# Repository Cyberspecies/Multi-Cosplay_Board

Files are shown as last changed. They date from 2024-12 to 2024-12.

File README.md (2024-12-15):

# Multi-Cosplay_Board
The board should be capable of driving nearly any electrically active cosplay suit or project including props. The system must also remain cheap and affordable with inter and extrapolation capabilities allowing it to be reducibly complex and still function. The software must also be easy to configure and implement (as this is a platform supported by [ARCOS](https://github.com/XCR1793/ARCOS)).

## Features
* Movement detection via the [ICM-20948](https://invensense.tdk.com/products/motion-tracking/9-axis/icm-20948/), which allows users to track their linear and angular accelerations for animations that require shaking, turning or any other activity requiring user displacement.
* Designed with a small form-factor which users can take advantage of by hiding the circuit board in tight spaces to not get it in the way of aesthetics.
* Fast processing core being the [ESP32-S3 Modules](https://www.espressif.com/en/products/socs/esp32) contains a 280Mhz dual core processor allowing partial asynchronous parallel calculations required for detecting user input and computing sequences at the same time whilst remaining as affordable as possible.

## Roadmap
* Milestone: Nothing Yet
* Work In Progress: Ideation & PCB Component Placement & Feature Integration
* Planned: MCB Version 1
* Planned: ARCOS Integration

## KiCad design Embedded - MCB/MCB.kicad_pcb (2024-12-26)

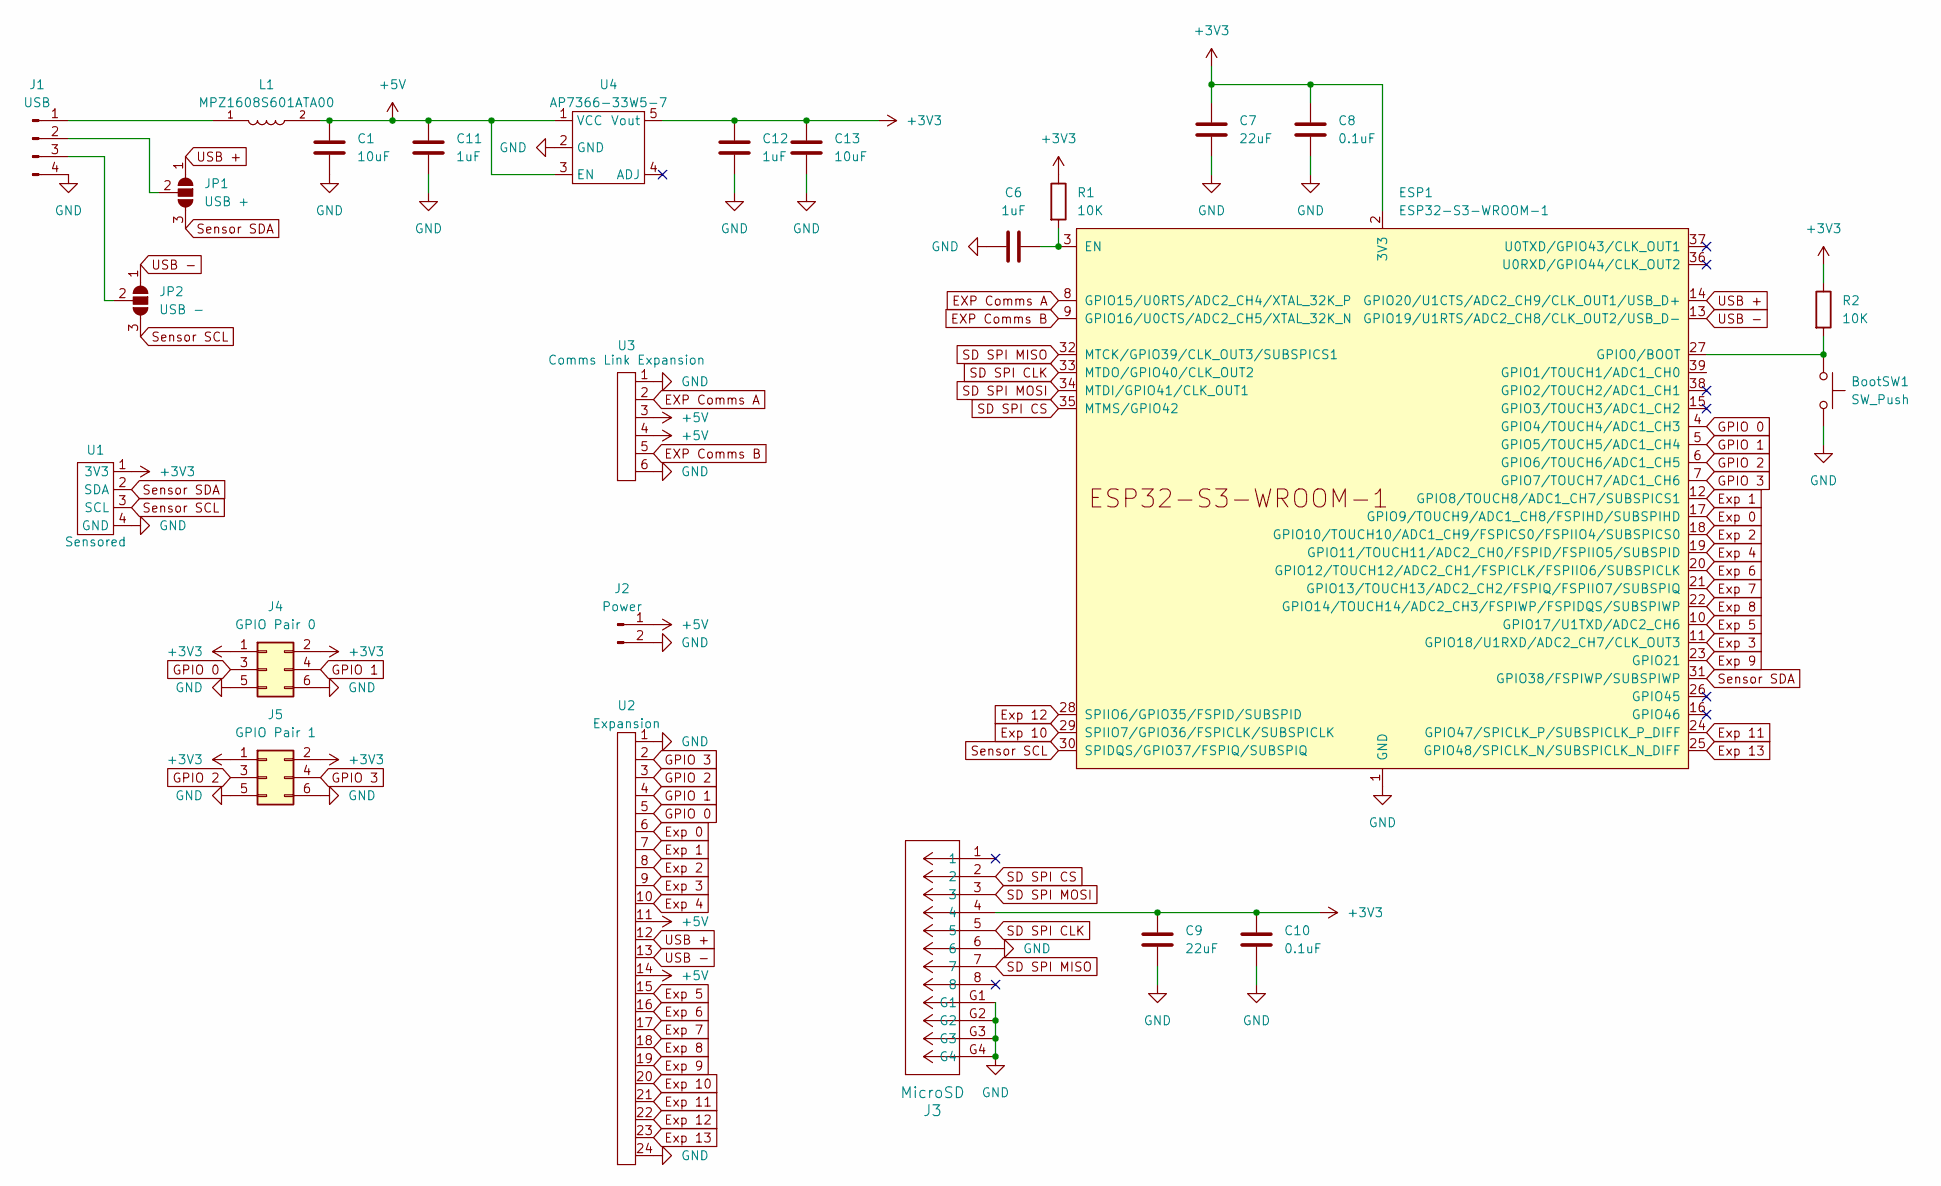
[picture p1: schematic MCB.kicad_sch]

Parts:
BootSW1: SW_Push; Button-R-667843
C1, C13: 10uF; C_0603_1608Metric
C6: 1uF; C_0603_1608Metric
C7, C9: 22uF; C_0603_1608Metric_Pad1.08x0.95mm_HandSolder
C8, C10: 0.1uF; C_0603_1608Metric_Pad1.08x0.95mm_HandSolder
C11, C12: 1uF; R_0603_1608Metric
ESP1: ESP32-S3-WROOM-1; ESP32-S3-WROOM-1U
J1: USB; Hirose_DF13-04P-1.25DS_1x04_P1.25mm_Horizontal
J2: Power; Hirose_DF13-02P-1.25DS_1x02_P1.25mm_Horizontal
J3: MicroSD; CONN12_47309-2651_MOL
J4: GPIO Pair 0; PinHeader_2x03_P2.54mm_Vertical
J5: GPIO Pair 1; PinHeader_2x03_P2.54mm_Vertical
JP1: USB +; SolderJumper-3_P1.3mm_Open_RoundedPad1.0x1.5mm
JP2: USB -; SolderJumper-3_P1.3mm_Open_RoundedPad1.0x1.5mm
L1: MPZ1608S601ATA00; INDC1608X95N
R1, R2: 10K; R_0603_1608Metric
U1: Sensored
U2: Expansion; FFC Aliexpress 0.5mm 24P
U3: Comms Link Expansion; FFC Aliexpress 0.5mm 6P
U4: AP7366-33W5-7; AP7366

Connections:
+3V3: C7.1, C8.1, C9.1, C10.1, C12.1, C13.1, ESP1.2 (3V3), J3.4, J4.1, J4.2, J5.1, J5.2, R1.1, R2.1, U1.1 (3V3), U4.5 (Vout)
+5V: C1.1, C11.1, J2.1, L1.2, U2.11, U2.14, U3.3, U3.4, U4.1 (VCC), U4.3 (EN)
EXP Comms A: ESP1.8 (GPIO15/U0RTS/ADC2_CH4/XTAL_32K_P), U3.2
EXP Comms B: ESP1.9 (GPIO16/U0CTS/ADC2_CH5/XTAL_32K_N), U3.5
Exp 0: ESP1.17 (GPIO9/TOUCH9/ADC1_CH8/FSPIHD/SUBSPIHD), U2.6
Exp 1: ESP1.12 (GPIO8/TOUCH8/ADC1_CH7/SUBSPICS1), U2.7
Exp 2: ESP1.18 (GPIO10/TOUCH10/ADC1_CH9/FSPICS0/FSPIIO4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), U2.8
Exp 3: ESP1.11 (GPIO18/U1RXD/ADC2_CH7/CLK_OUT3), U2.9
Exp 4: ESP1.19 (GPIO11/TOUCH11/ADC2_CH0/FSPID/FSPIIO5/S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), U2.10
Exp 5: ESP1.10 (GPIO17/U1TXD/ADC2_CH6), U2.15
Exp 6: ESP1.20 (GPIO12/TOUCH12/ADC2_CH1/FSPICLK/FSPIIO6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), U2.16
Exp 7: ESP1.21 (GPIO13/TOUCH13/ADC2_CH2/FSPIQ/FSPIIO7/S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), U2.17
Exp 8: ESP1.22 (GPIO14/TOUCH14/ADC2_CH3/FSPIWP/FSPIDQS/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), U2.18
Exp 9: ESP1.23 (GPIO21), U2.19
Exp 10: ESP1.29 (SPIIO7/GPIO36/FSPICLK/SUBSPICLK), U2.20
Exp 11: ESP1.24 (GPIO47/SPICLK_P/SUBSPICLK_P_DIFF), U2.21
Exp 12: ESP1.28 (SPIIO6/GPIO35/FSPID/SUBSPID), U2.22
Exp 13: ESP1.25 (GPIO48/SPICLK_N/SUBSPICLK_N_DIFF), U2.23
GND: BootSW1.2, C1.2, C6.1, C7.2, C8.2, C9.2, C10.2, C11.2, C12.2, C13.2, ESP1.1 (GND), ESP1.40 (GND), ESP1.41 (GND), J1.4, J2.2, J3.6, J3.G1, J3.G2, J3.G3, J3.G4, J4.5, J4.6, J5.5, J5.6, U1.4 (GND), U2.1, U2.24, U3.1, U3.6, U4.2 (GND)
GPIO 0: ESP1.4 (GPIO4/TOUCH4/ADC1_CH3), J4.3, U2.5
GPIO 1: ESP1.5 (GPIO5/TOUCH5/ADC1_CH4), J4.4, U2.4
GPIO 2: ESP1.6 (GPIO6/TOUCH6/ADC1_CH5), J5.3, U2.3
GPIO 3: ESP1.7 (GPIO7/TOUCH7/ADC1_CH6), J5.4, U2.2
unnamed: C6.2, ESP1.3 (EN), R1.2
unnamed: BootSW1.1, ESP1.27 (GPIO0/BOOT), R2.2
unnamed: J1.1, L1.1
unnamed: J1.2, JP1.2 (C)
unnamed: J1.3, JP2.2 (C)
SD SPI CLK: ESP1.33 (MTDO/GPIO40/CLK_OUT2), J3.5
SD SPI CS: ESP1.35 (MTMS/GPIO42), J3.2
SD SPI MISO: ESP1.32 (MTCK/GPIO39/CLK_OUT3/SUBSPICS1), J3.7
SD SPI MOSI: ESP1.34 (MTDI/GPIO41/CLK_OUT1), J3.3
Sensor SCL: ESP1.30 (SPIDQS/GPIO37/FSPIQ/SUBSPIQ), JP2.3 (B), U1.3 (SCL)
Sensor SDA: ESP1.31 (GPIO38/FSPIWP/SUBSPIWP), JP1.3 (B), U1.2 (SDA)
USB +: ESP1.14 (GPIO20/U1CTS/ADC2_CH9/CLK_OUT1/USB_D+), JP1.1 (A), U2.12
USB -: ESP1.13 (GPIO19/U1RTS/ADC2_CH8/CLK_OUT2/USB_D-), JP2.1 (A), U2.13

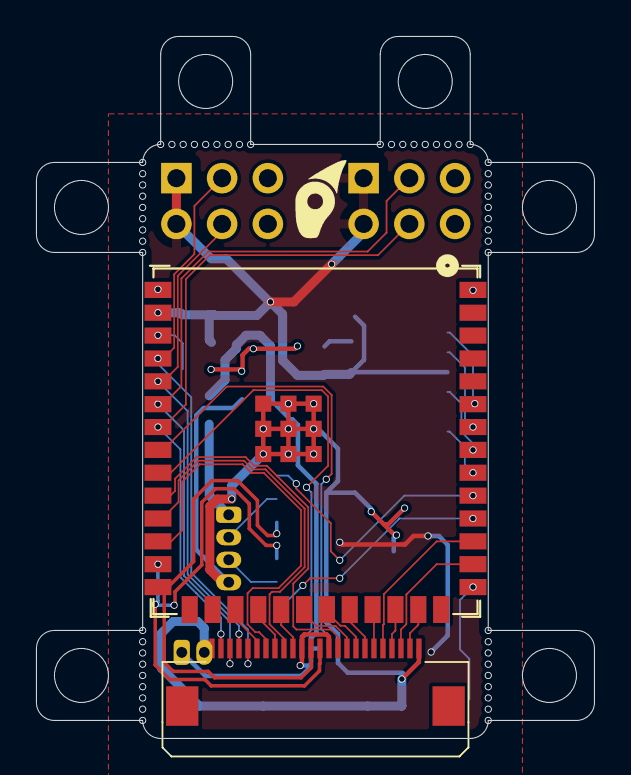
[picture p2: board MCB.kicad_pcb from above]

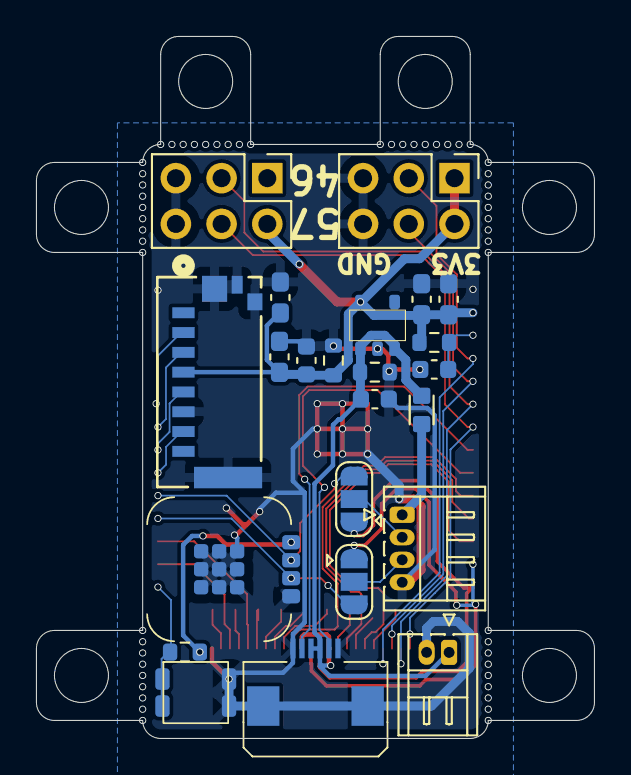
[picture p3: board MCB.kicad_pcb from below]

Board: 2 copper layers, 31.0 x 39.0 mm, 25 parts (23 on the bottom side), 36 nets.

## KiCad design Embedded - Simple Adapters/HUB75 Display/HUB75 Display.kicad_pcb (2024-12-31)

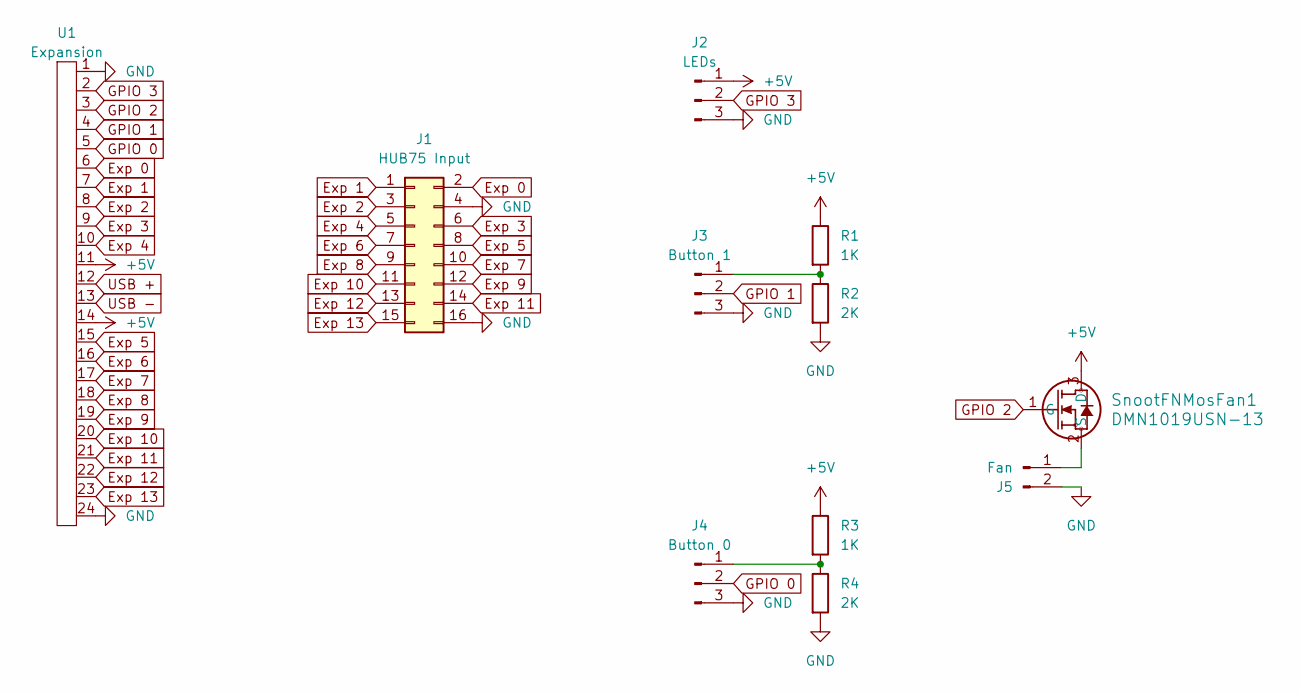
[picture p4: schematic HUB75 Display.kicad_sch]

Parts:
J1: HUB75 Input; PinHeader_2x08_P2.54mm_Vertical
J2: LEDs; PinHeader_1x03_P2.54mm_Vertical
J3: Button 1; PinHeader_1x03_P2.54mm_Vertical
J4: Button 0; PinHeader_1x03_P2.54mm_Vertical
J5: Fan; PinHeader_1x02_P2.54mm_Vertical
R1, R3: 1K; R_0603_1608Metric_Pad0.98x0.95mm_HandSolder
R2, R4: 2K; R_0603_1608Metric_Pad0.98x0.95mm_HandSolder
SnootFNMosFan1: DMN1019USN-13; SOT-23-3
U1: Expansion; FFC Aliexpress 0.5mm 24P

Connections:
+5V: J2.1, R1.1, R3.1, SnootFNMosFan1.3 (D), U1.11, U1.14
Exp 0: J1.2, U1.6
Exp 1: J1.1, U1.7
Exp 2: J1.3, U1.8
Exp 3: J1.6, U1.9
Exp 4: J1.5, U1.10
Exp 5: J1.8, U1.15
Exp 6: J1.7, U1.16
Exp 7: J1.10, U1.17
Exp 8: J1.9, U1.18
Exp 9: J1.12, U1.19
Exp 10: J1.11, U1.20
Exp 11: J1.14, U1.21
Exp 12: J1.13, U1.22
Exp 13: J1.15, U1.23
GND: J1.4, J1.16, J2.3, J3.3, J4.3, J5.2, R2.2, R4.2, U1.1, U1.24
GPIO 0: J4.2, U1.5
GPIO 1: J3.2, U1.4
GPIO 2: SnootFNMosFan1.1 (G), U1.3
GPIO 3: J2.2, U1.2
unnamed: J3.1, R1.2, R2.1
unnamed: J4.1, R3.2, R4.1
unnamed: J5.1, SnootFNMosFan1.2 (S)
USB +: U1.12
USB -: U1.13

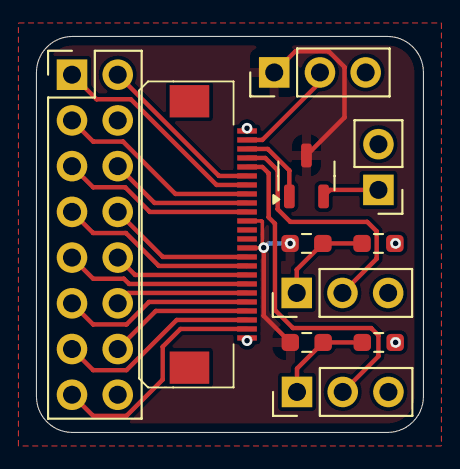
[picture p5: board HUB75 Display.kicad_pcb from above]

Board: 2 copper layers, 21.5 x 22.0 mm, 11 parts (0 on the bottom side), 23 nets.

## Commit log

2024-12-15 Ideation of PCB Layout and Function
    [MCB Ideation.kicad_pcb, MCB Ideation.kicad_sch]
2024-12-15 Ideation PCB Component Compaction
    [MCB Ideation.kicad_pcb, MCB Ideation.kicad_sch]
2024-12-16 Feature Listing & Organisation
    [Ideation.ods, MCB Ideation.kicad_sch]
2024-12-16 Fixed Broken 3D Models
    [MCB Ideation.kicad_pcb]
2024-12-24 Added Sensored
    [MCB Ideation.kicad_pcb, MCB Ideation.kicad_sch]
2024-12-24 Added Expansion Pins
    [MCB Ideation.kicad_pcb, MCB Ideation.kicad_sch]
2024-12-24 Added USB Connectivity & Verified Expansion Pins
    [MCB Ideation.kicad_pcb]
2024-12-24 Added Secondary Expansion (Comms Link)
    [MCB Ideation.kicad_pcb, MCB Ideation.kicad_sch]
2024-12-25 Added USB and Power Ports
    [MCB Ideation.kicad_pcb, MCB Ideation.kicad_sch]
2024-12-25 Rerouted Some Components
    [MCB Ideation.kicad_pcb, MCB Ideation.kicad_sch]
2024-12-25 Added GPIO Pins
    [MCB Ideation.kicad_sch]
2024-12-25 Modified GPIO Expansion Pins
    [MCB Ideation.kicad_pcb, MCB Ideation.kicad_sch]
2024-12-26 Added Substructure Adapter & Extended MCB Expansion Pins
    [MCB Ideation.kicad_pcb, MCB Ideation.kicad_sch, MCB.kicad_pcb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]
2024-12-26 Added USB-2WComms Solder Bridge
    [MCB.kicad_pcb, MCB.kicad_sch, Substructure.kicad_sch]
2024-12-26 Modified Some Traces for Lower Noise
    [MCB.kicad_pcb]
2024-12-26 Migrated Substructure
    The substructure KiCAD files were migrated to another repo as it was directly part of the MCB
    [MCB.kicad_pcb, MCB.kicad_sch, Substructure.kicad_pcb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]
2024-12-31 Added Combined Fabrication Files for (MCB, Substructure, Display, UI and HUB75)
    [HUB75 Display.kicad_pcb, HUB75 Display.kicad_sch, MCB.kicad_pcb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]
